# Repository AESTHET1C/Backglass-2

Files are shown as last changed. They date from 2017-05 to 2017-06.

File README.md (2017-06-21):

# Backglass 2 Pinball Controller Board

An Arduino Uno-compatible unified control board tailored to the Eli Whitney Museum 2017 summer pinball project.

The board contains the following hardware:

* Microchip ATmega8U2/16U2 (serial communication and code upload)
* Microchip ATmega328P (user code)
* Microchip ATmega48PB (audio/visual coprocessing)
* 4-character 7 segment display
* 2 analogue inputs (for reflectance sensors)
* 5 digital inputs (with integrated pull-ups)
* 3 current-limited LED outputs
* 1 PWM-controlled motor output
* 1 speaker output
* Micro USB interface
* 2.7 - 6.5 volt power input

All features of the board, with the exception of the motor, can be powered via USB.

-----

A user-oriented code library can be found here: <https://github.com/AESTHET1C/Backglass-2-Library/>

The coprocessor firmware can be found here: <https://github.com/AESTHET1C/Backglass-2-Firmware/>

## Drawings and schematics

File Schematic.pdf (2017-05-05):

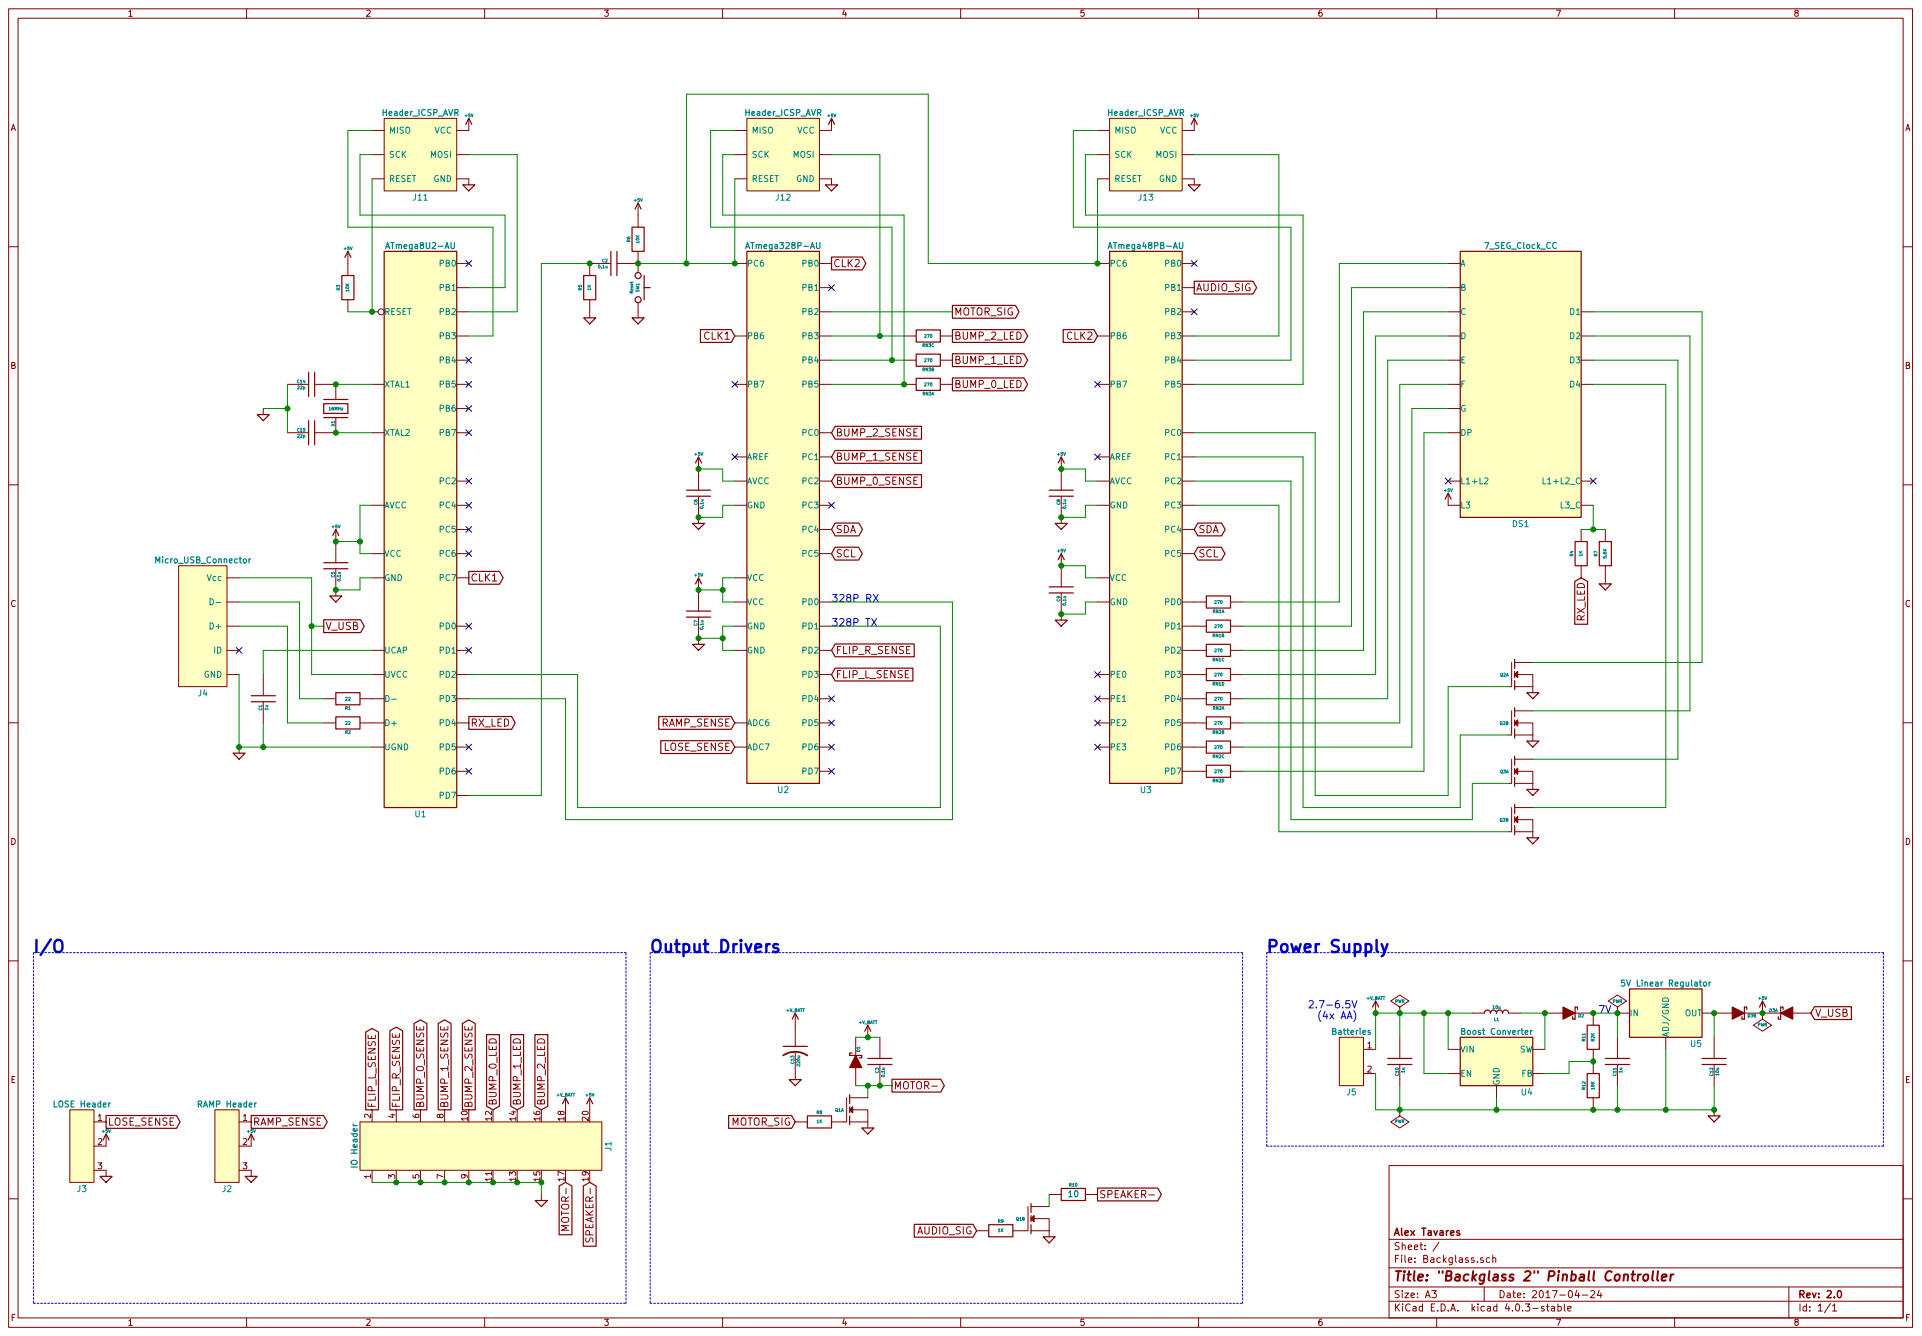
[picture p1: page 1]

9 1020 11 12 13 14 15 16 17 18 19 J1 IO Header FLIP_L_SENSE FLIP_R_SENSE BUMP_0_SENSE BUMP_1_SENSE BUMP_2_SENSE BUMP_0_LED BUMP_1_LED BUMP_2_LED SPEAKER- MOTOR-

File: Backglass.sch Sheet: / Alex Tavares

Id: 1/1 Title: "Backglass 2" Pinball Controller

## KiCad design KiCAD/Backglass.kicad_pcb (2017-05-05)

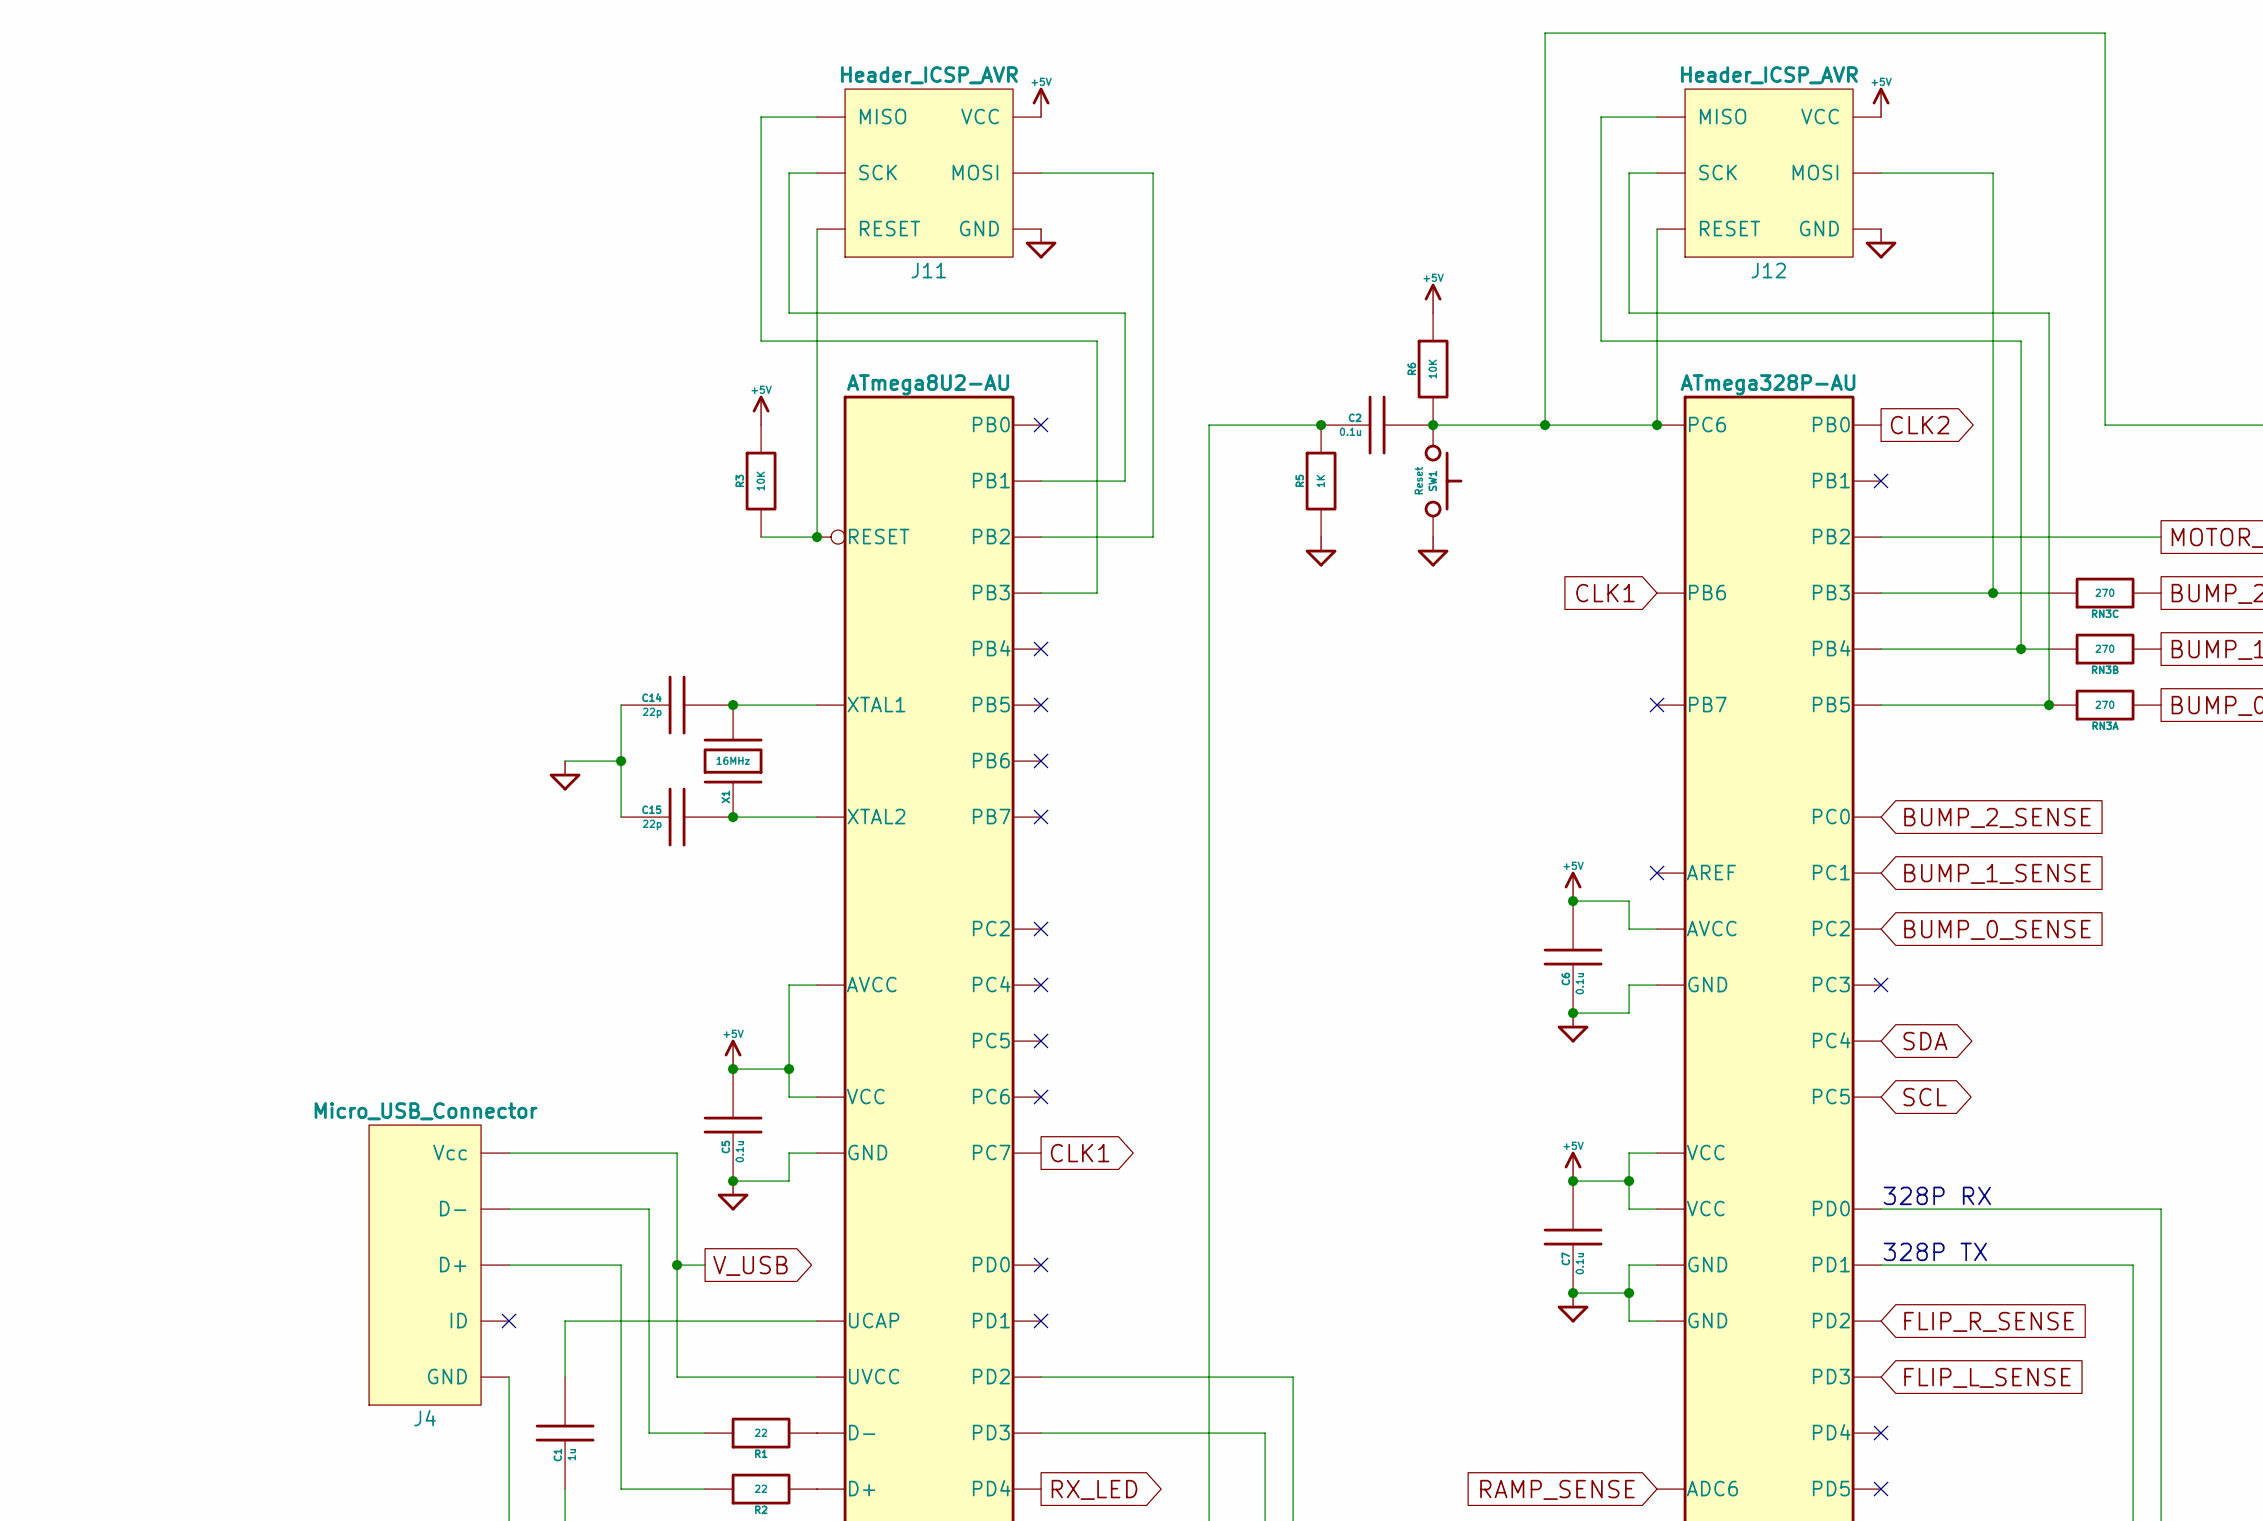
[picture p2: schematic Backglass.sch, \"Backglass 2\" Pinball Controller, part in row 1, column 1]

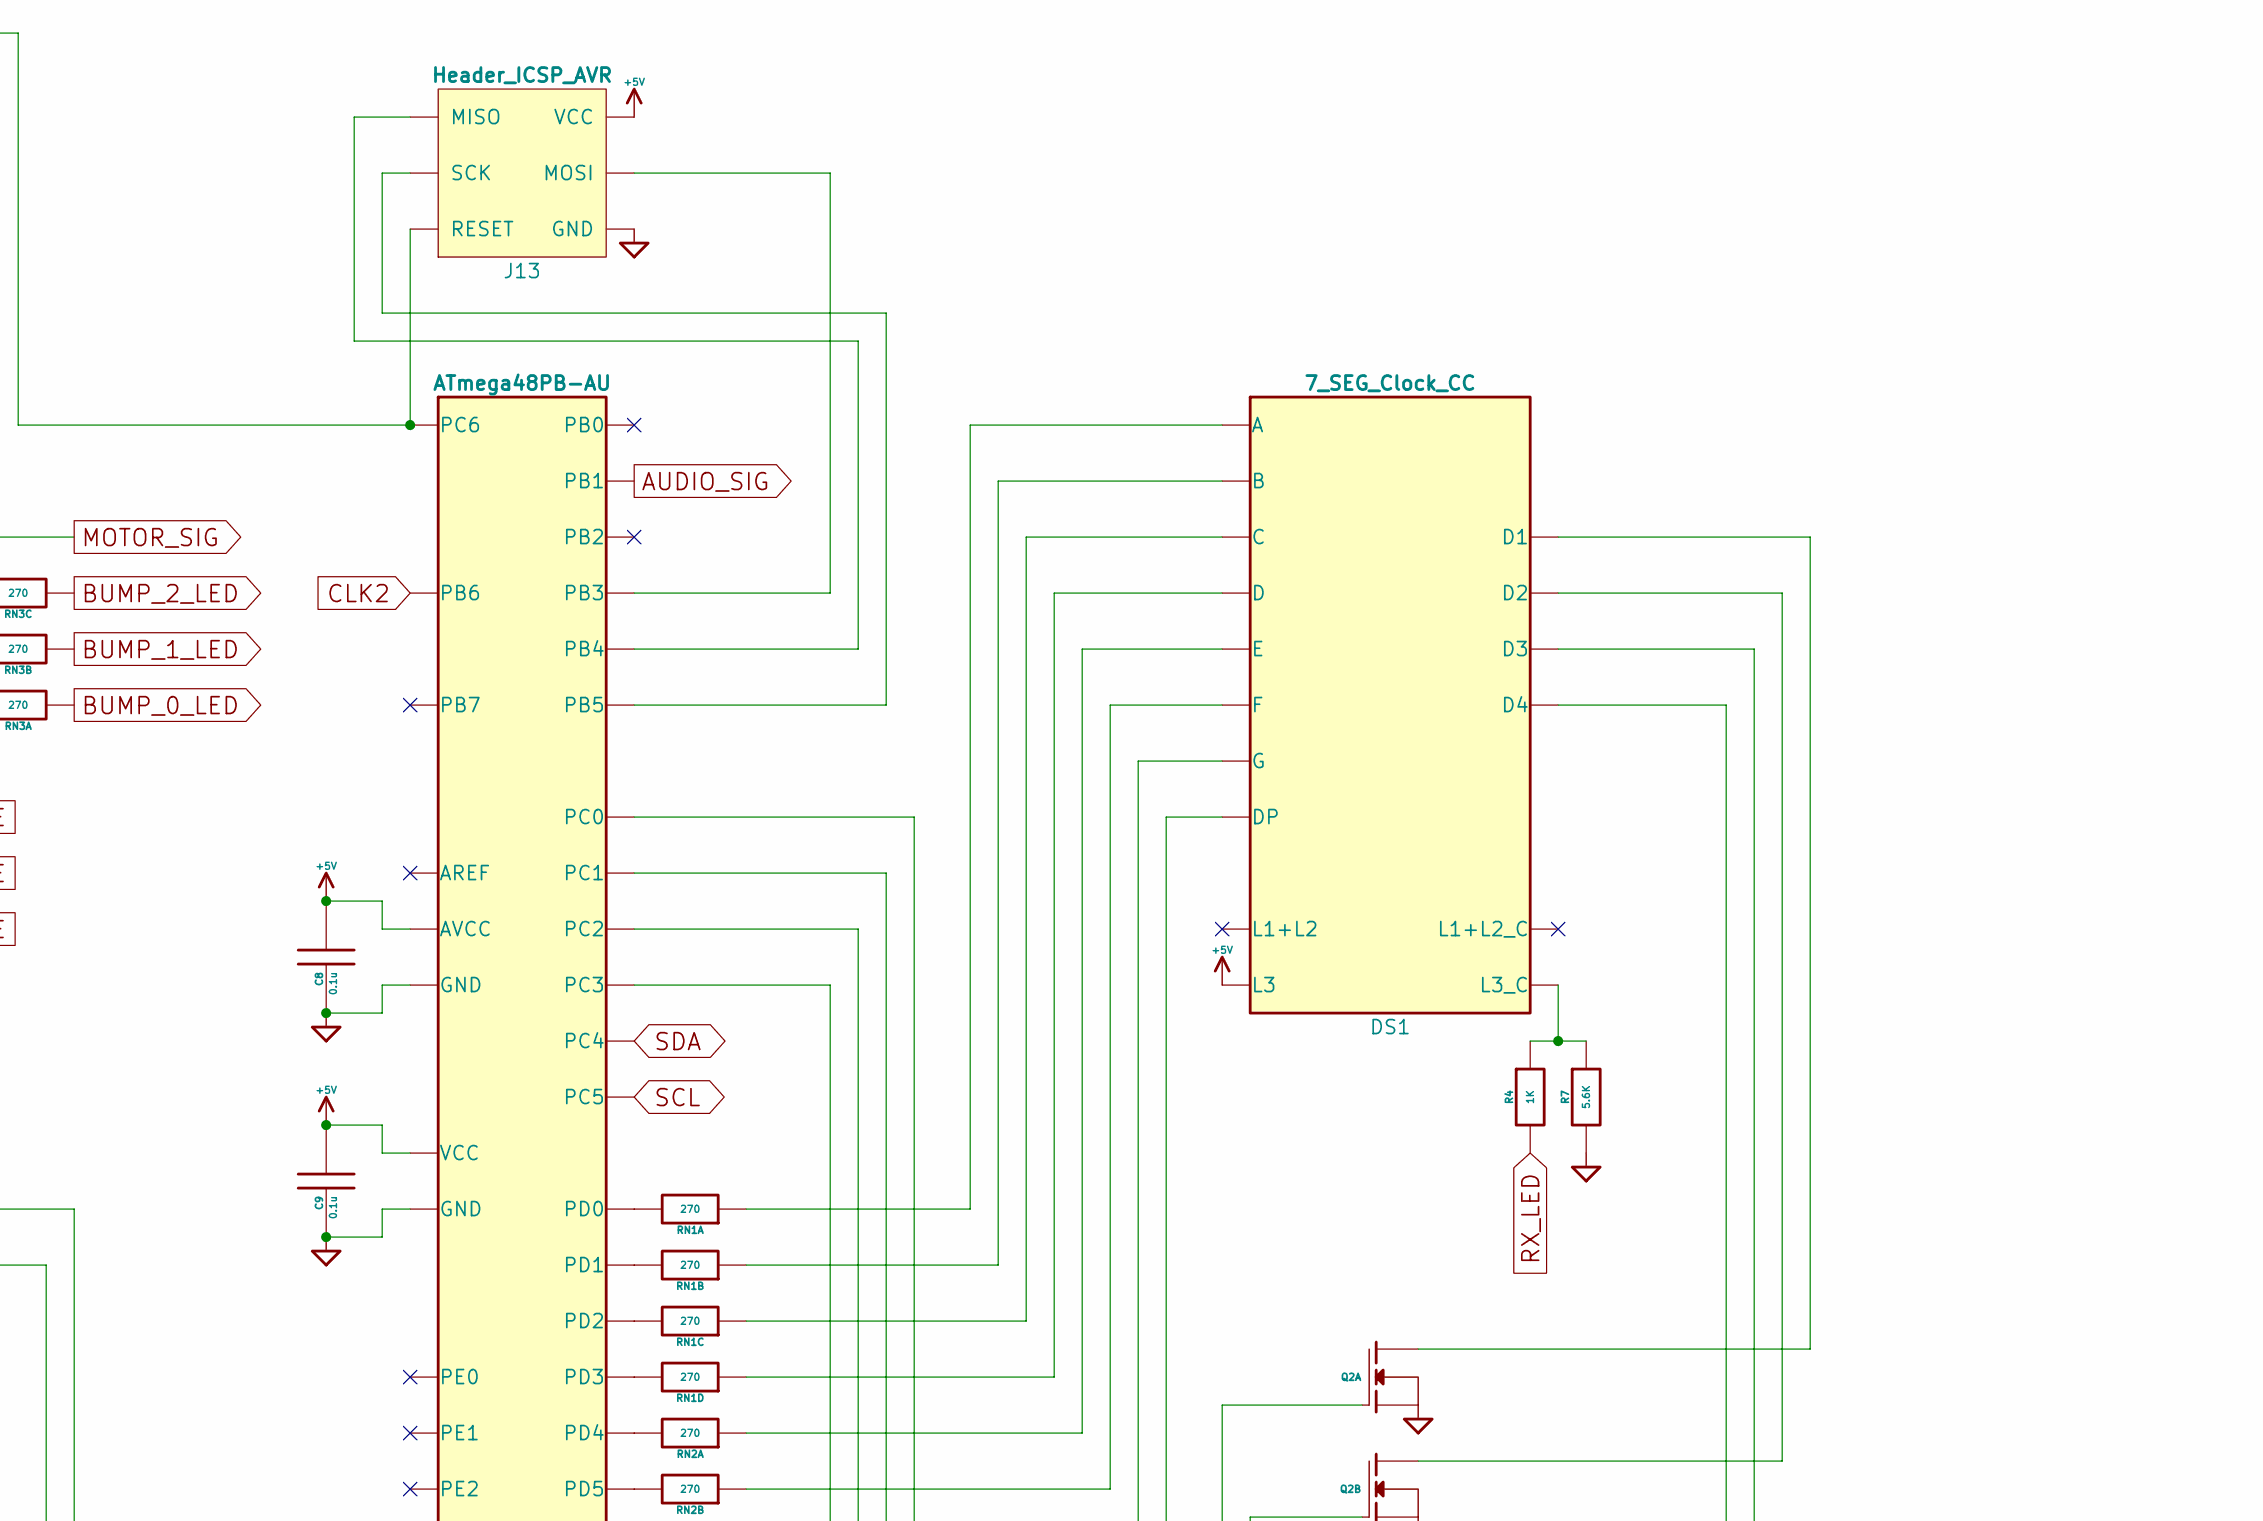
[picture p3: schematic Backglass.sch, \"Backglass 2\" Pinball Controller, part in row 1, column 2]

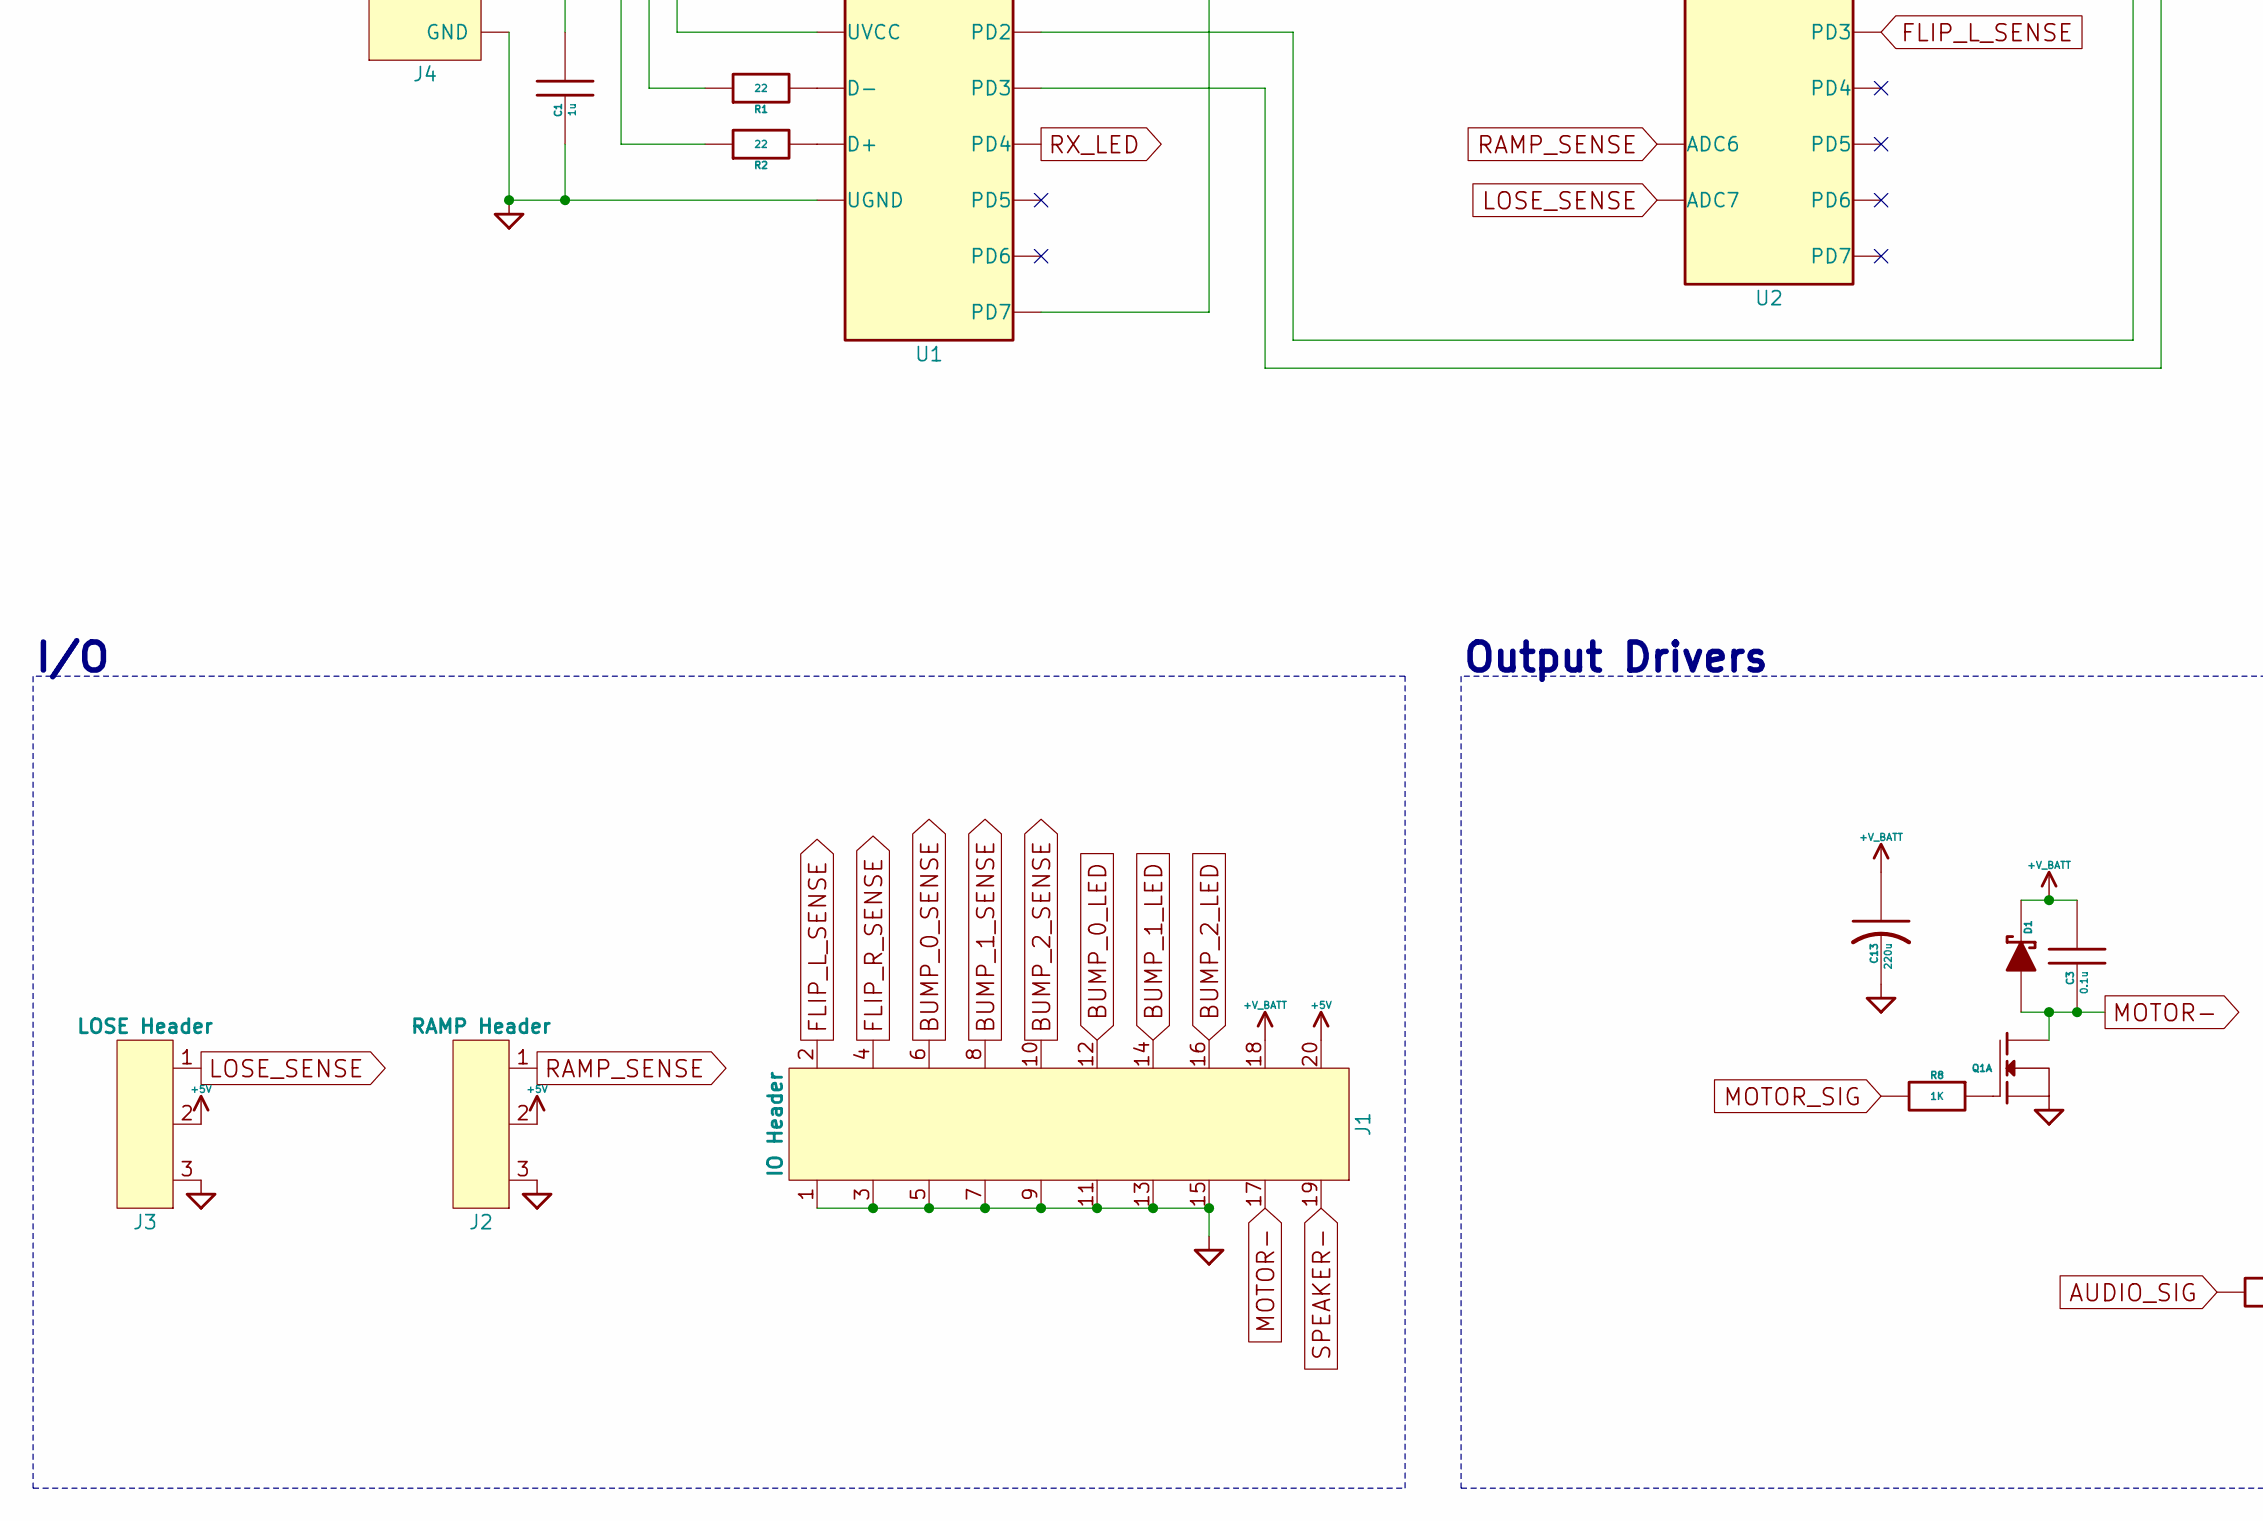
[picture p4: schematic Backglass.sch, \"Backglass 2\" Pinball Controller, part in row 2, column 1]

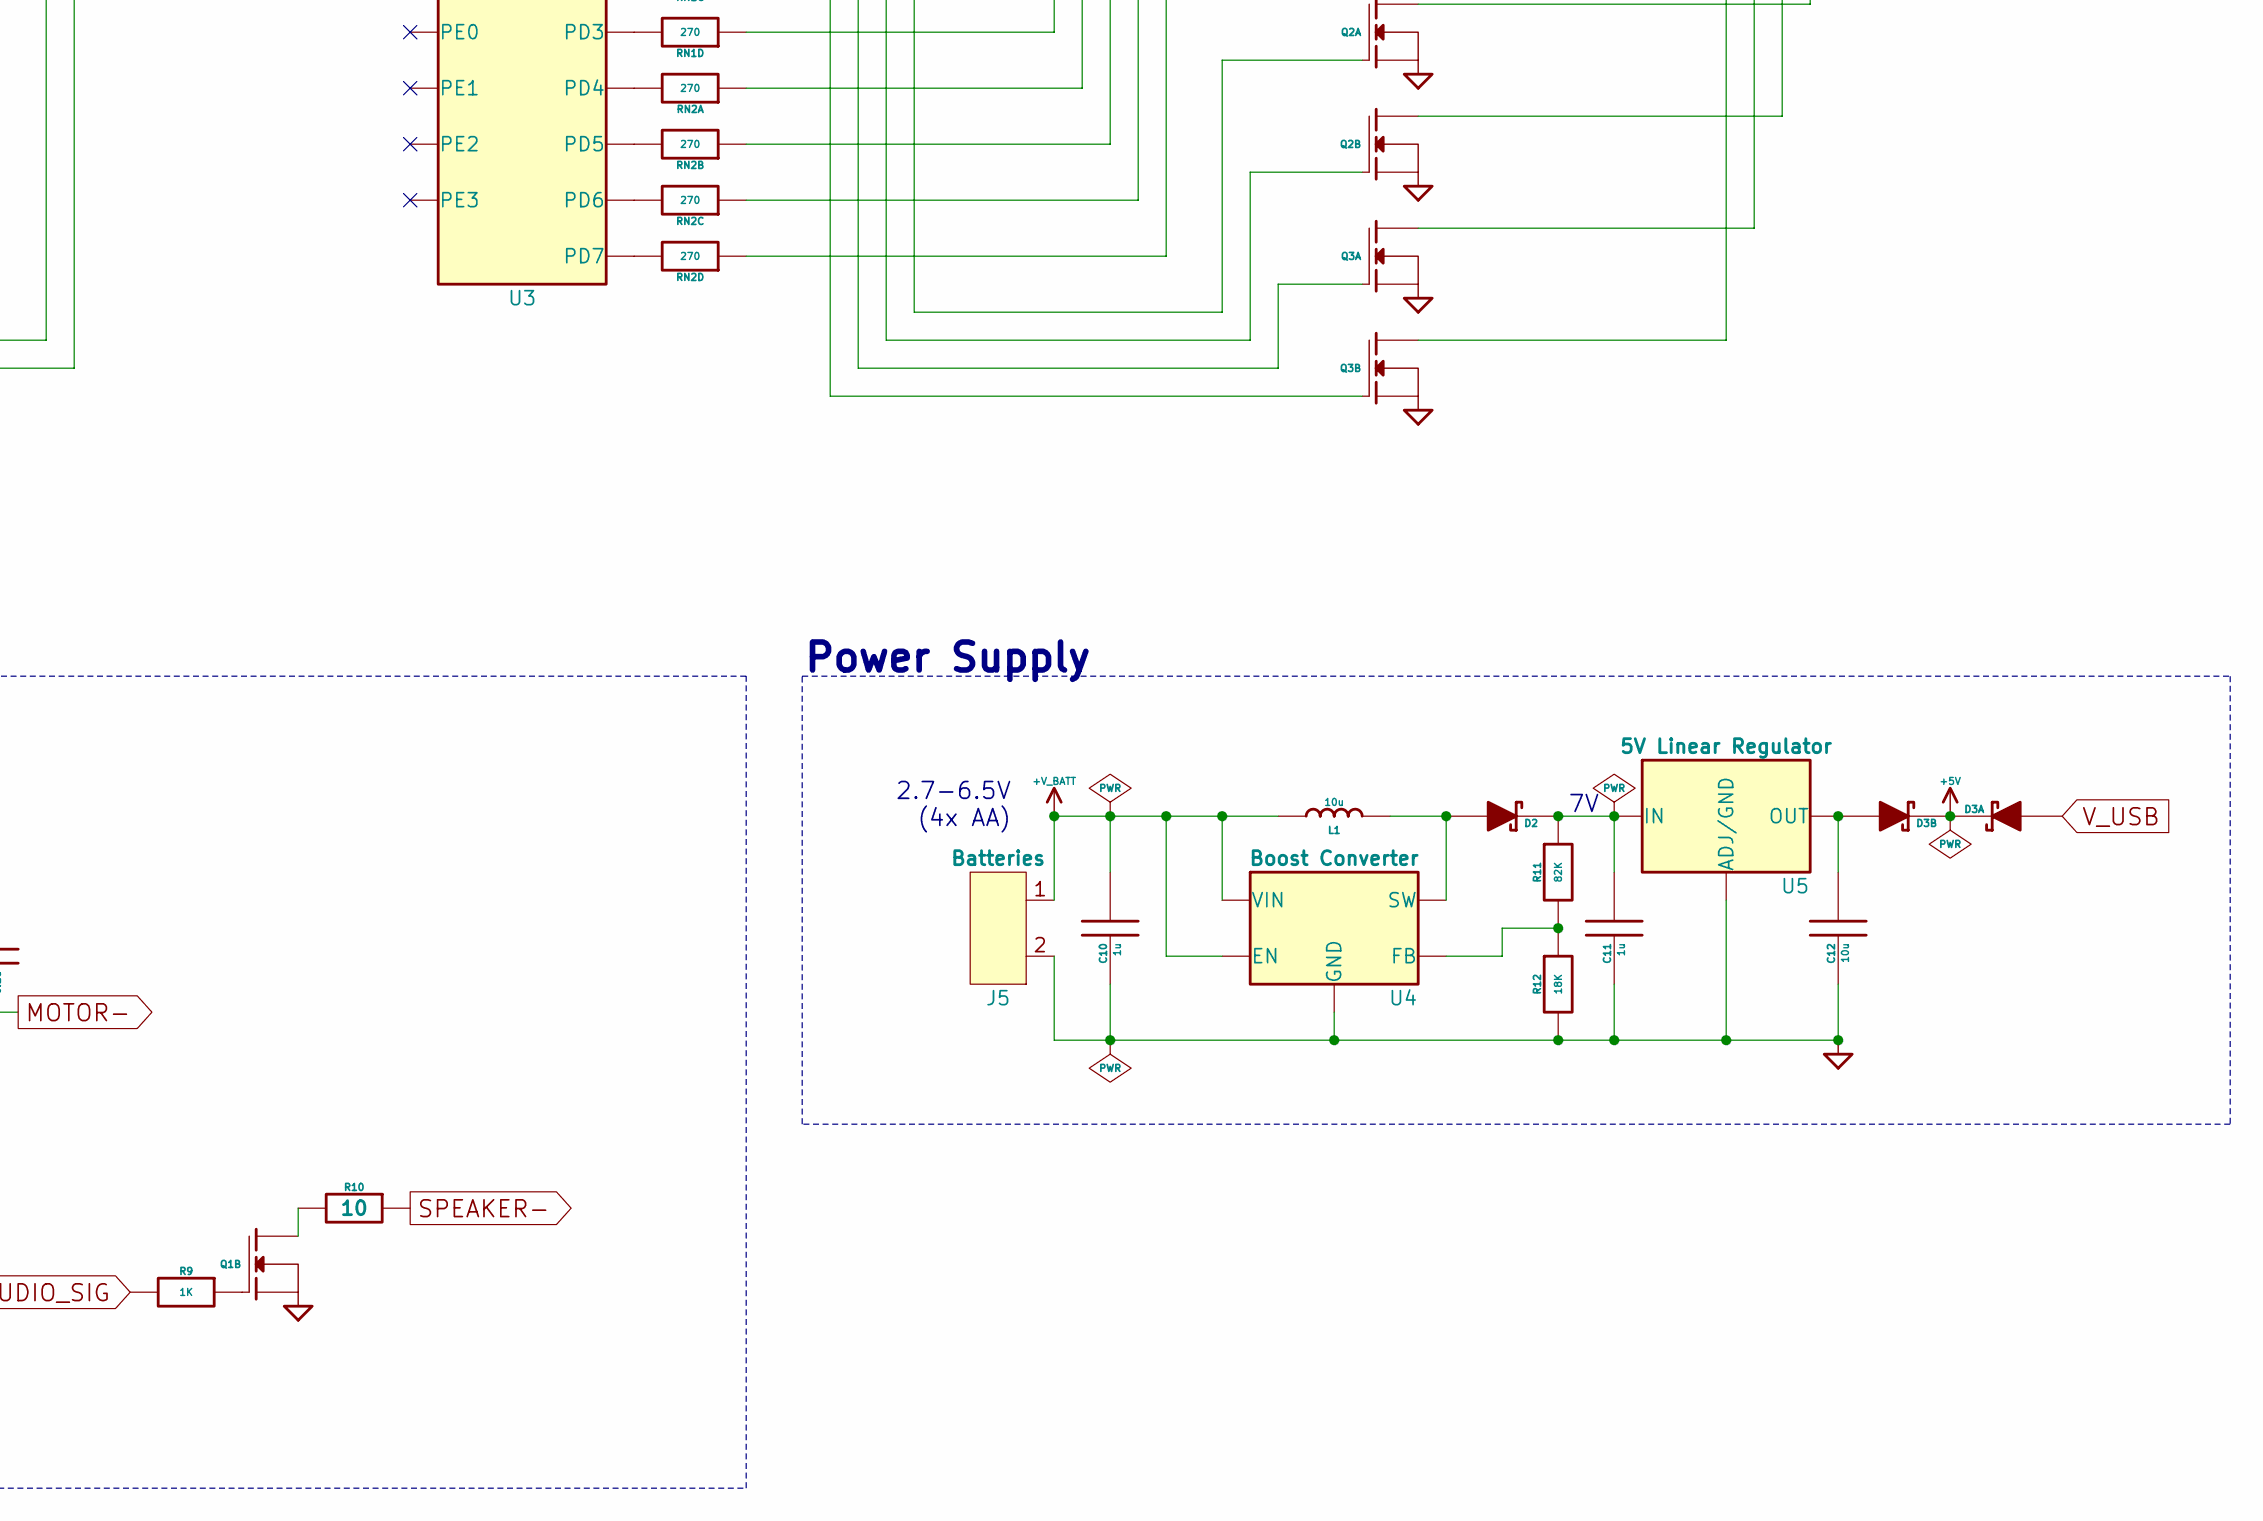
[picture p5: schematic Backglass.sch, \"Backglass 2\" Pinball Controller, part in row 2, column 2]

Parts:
C1, C10, C11: 1u; 1608
C2, C3, C5, C6, C7, C8, C9: 0.1u; 1608
C12: 10u; 2012
C13: 220u; C_6.3-2.5mm
C14, C15: 22p; 1608
D1, D2: D_Schottky; SOT-23-3_A-C
D3: D_Schottky_Dual_CC; SOT-23-3_AAC
DS1: 7_SEG_Clock_CC; TDCx10xxM
J1: IO Header; 10x2_0.1in
J2: RAMP Header; 3x1_0.1in
J3: LOSE Header; 3x1_0.1in
J4: Micro_USB_Connector; Molex_1051640001
J5: Batteries; 2x1_0.1in
J11, J12, J13: Header_ICSP_AVR; AVR_ICSP_0.05in
L1: 10u; 3225
Q1: MOSFET_N_E_Dual; SOT-23-6_G1-S2-G2-D2-S1-D1
Q2, Q3: MOSFET_N_E_Dual; TSSOP-6_S1-G1-D2-S2-G2-D1
R1, R2: 22; 1608
R3, R6: 10K; 1608
R4, R5, R8, R9: 1K; 1608
R7: 5.6K; 1608
R10: 10; 3225
R11: 82K; 1608
R12: 18K; 1608
RN1, RN2, RN3: 270; Array_4x1608_Convex_NP
SW1: Reset; Tact_Switch_6mm
U1: ATmega8U2-AU; TQFP-32
U2: ATmega328P-AU; TQFP-32
U3: ATmega48PB-AU; TQFP-32
U4: Boost Converter; SOT-23-5
U5: 5V Linear Regulator; SOT-223-4
X1: 16MHz; 3.2x2.5_SMD_CRYSTAL

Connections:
+5V: C5.2, C6.2, C7.2, C8.2, C9.2, D3.C, DS1.9 (L3), J1.20, J2.2, J3.2, J11.2 (VCC), J12.2 (VCC), J13.2 (VCC), R3.1, R6.1, U1.4 (VCC), U1.32 (AVCC), U2.4 (VCC), U2.6 (VCC), U2.18 (AVCC), U3.4 (VCC), U3.18 (AVCC)
+V_BATT: C3.2, C10.2, C13.1, D1.C, J1.18, J5.1, L1.1, U4.4 (EN), U4.5 (VIN)
AUDIO_SIG: R9.2, U3.13 (PB1)
BUMP_0_LED: J1.12, RN3.8
BUMP_0_SENSE: J1.6, U2.25 (PC2)
BUMP_1_LED: J1.14, RN3.7
BUMP_1_SENSE: J1.8, U2.24 (PC1)
BUMP_2_LED: J1.16, RN3.6
BUMP_2_SENSE: J1.10, U2.23 (PC0)
CLK1: U1.22 (PC7), U2.7 (PB6)
CLK2: U2.12 (PB0), U3.7 (PB6)
FLIP_L_SENSE: J1.2, U2.1 (PD3)
FLIP_R_SENSE: J1.4, U2.32 (PD2)
GND: C1.1, C5.1, C6.1, C7.1, C8.1, C9.1, C10.1, C11.1, C12.1, C13.2, C14.1, C15.1, J1.1, J1.3, J1.5, J1.7, J1.9, J1.11, J1.13, J1.15, J2.3, J3.3, J4.5 (GND), J5.2, J11.6 (GND), J12.6 (GND), J13.6 (GND), Q1.S1, Q1.S2, Q2.S1, Q2.S2, Q3.S1, Q3.S2, R5.2, R7.2, R12.2, SW1.2 (NO), U1.3 (GND), U1.28 (UGND), U2.3 (GND), U2.5 (GND), U2.21 (GND), U3.5 (GND), U3.21 (GND), U4.2 (GND), U5.1 (ADJ/GND)
LOSE_SENSE: J3.1, U2.22 (ADC7)
MOTOR-: C3.1, D1.A, J1.17, Q1.D1
MOTOR_SIG: R8.2, U2.14 (PB2)
unnamed: C1.2, U1.27 (UCAP)
unnamed: C2.1, R5.1, U1.13 (PD7)
unnamed: C2.2, J12.5 (RESET), J13.5 (RESET), R6.2, SW1.1 (C), U2.29 (PC6), U3.29 (PC6)
unnamed: C11.2, D2.C, R11.1, U5.3 (IN)
unnamed: C12.2, D3.A2, U5.2 (OUT), U5.4
unnamed: C14.2, U1.1 (XTAL1), X1.2
unnamed: C15.2, U1.2 (XTAL2), X1.1
unnamed: D2.A, L1.2, U4.1 (SW)
unnamed: DS1.1 (D1), Q2.D1
unnamed: DS1.2 (D2), Q2.D2
unnamed: DS1.3 (D), RN1.4
unnamed: DS1.5 (E), RN2.1
unnamed: DS1.6 (D3), Q3.D1
unnamed: DS1.7 (DP), RN2.4
unnamed: DS1.8 (D4), Q3.D2
unnamed: DS1.10 (L3_C), R4.1, R7.1
unnamed: DS1.11 (F), RN2.2
unnamed: DS1.13 (C), RN1.3
unnamed: DS1.14 (A), RN1.1
unnamed: DS1.15 (G), RN2.3
unnamed: DS1.16 (B), RN1.2
unnamed: J4.2 (D-), R1.1
unnamed: J4.3 (D+), R2.1
unnamed: J11.1 (MISO), U1.17 (PB3)
unnamed: J11.3 (SCK), U1.15 (PB1)
unnamed: J11.4 (MOSI), U1.16 (PB2)
unnamed: J11.5 (RESET), R3.2, U1.24 (RESET)
unnamed: J12.1 (MISO), RN3.2, U2.16 (PB4)
unnamed: J12.3 (SCK), RN3.1, U2.17 (PB5)
unnamed: J12.4 (MOSI), RN3.3, U2.15 (PB3)
unnamed: J13.1 (MISO), U3.16 (PB4)
unnamed: J13.3 (SCK), U3.17 (PB5)
unnamed: J13.4 (MOSI), U3.15 (PB3)
unnamed: Q1.D2, R10.2
unnamed: Q1.G1, R8.1
unnamed: Q1.G2, R9.1
unnamed: Q2.G1, U3.23 (PC0)
unnamed: Q2.G2, U3.24 (PC1)
unnamed: Q3.G1, U3.25 (PC2)
unnamed: Q3.G2, U3.26 (PC3)
unnamed: R1.2, U1.30 (D-)
unnamed: R2.2, U1.29 (D+)
unnamed: R11.2, R12.1, U4.3 (FB)
unnamed: RN1.5, U3.1 (PD3)
unnamed: RN1.6, U3.32 (PD2)
unnamed: RN1.7, U3.31 (PD1)
unnamed: RN1.8, U3.30 (PD0)
unnamed: RN2.5, U3.11 (PD7)
unnamed: RN2.6, U3.10 (PD6)
unnamed: RN2.7, U3.9 (PD5)
unnamed: RN2.8, U3.2 (PD4)
unnamed: U1.8 (PD2), U2.31 (PD1)
unnamed: U1.9 (PD3), U2.30 (PD0)
RAMP_SENSE: J2.1, U2.19 (ADC6)
RX_LED: R4.2, U1.10 (PD4)
SCL: U2.28 (PC5), U3.28 (PC5)
SDA: U2.27 (PC4), U3.27 (PC4)
SPEAKER-: J1.19, R10.1
V_USB: D3.A1, J4.1 (Vcc), U1.31 (UVCC)

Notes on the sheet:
328P RX
328P TX
2.7-6.5V (4x AA)
Power Supply
I/O
Output Drivers

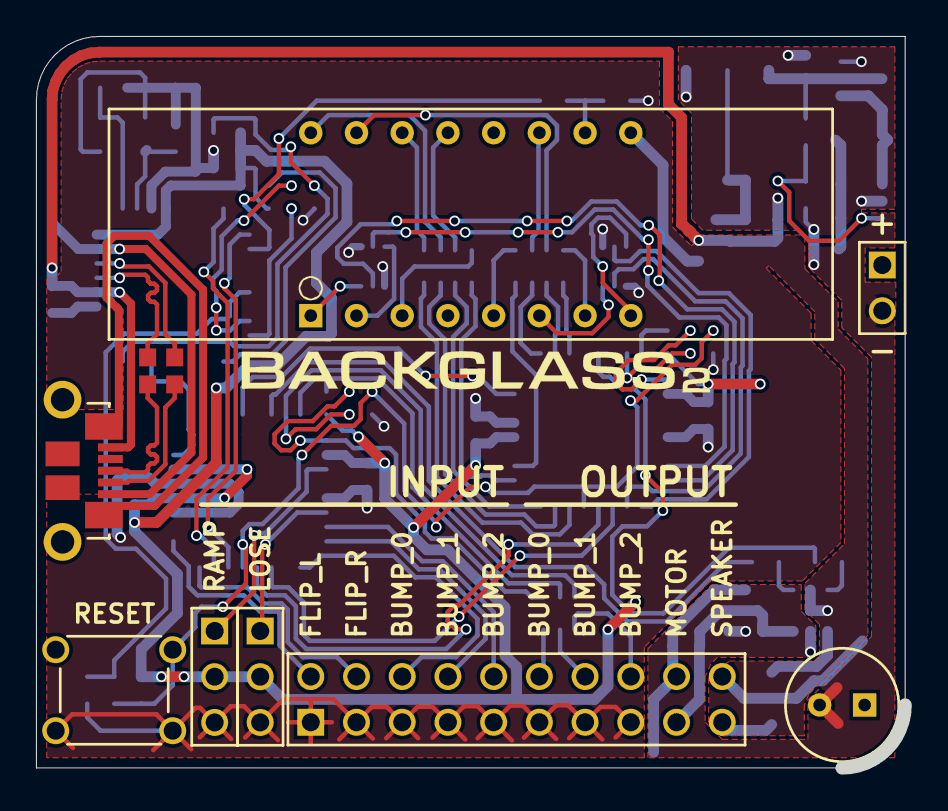
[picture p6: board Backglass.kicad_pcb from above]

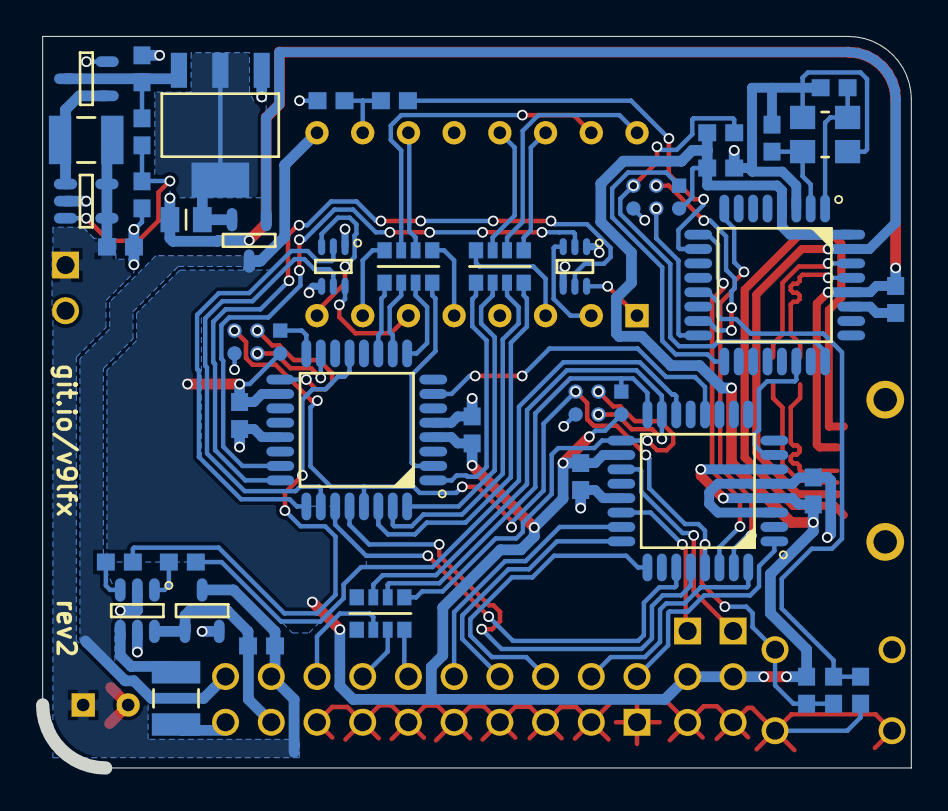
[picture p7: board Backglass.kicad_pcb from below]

Board: 2 copper layers, 48.3 x 40.6 mm, 52 parts (42 on the bottom side), 76 nets.

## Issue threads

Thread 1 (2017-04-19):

Missing mounting method

AESTHET1C, 2017-04-19:
Unlike the original Backglass board, there is no efficient way of mounting the board to the pinball machine.

AESTHET1C, 2017-05-05:
Mounting is to be handled either by hot glue or 3d-printed clips. I didn't feel like moving things around to fit mounting holes for the second revision, and I'm certainly not spinning a third revision just for that.

Closed 2017-05-05.

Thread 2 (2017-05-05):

Speaker driver causes reset on transition

AESTHET1C, 2017-05-05:
You did a bad job designing the half bridge and you should feel bad. Shoot-through is the first thing you should have considered when opting for bi-directional drive.

AESTHET1C, 2017-05-05:
The half bridge speaker drive has been removed and replaced with a boring single-transistor alternative for revision 2.0.

Closed 2017-05-05.

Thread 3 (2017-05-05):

Speaker output has DC offset

AESTHET1C, 2017-05-05:
Uni-directional drive and lack of AC coupling means speaker will always be driven positively. This may lead to long-term speaker damage.

Closed 2017-05-05.

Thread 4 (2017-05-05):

I2C lines lack pullups

AESTHET1C, 2017-05-05:

AESTHET1C, 2017-05-05:
I forgot to add pullups to the first revision of the board, and didn't feel like moving things around for the second revision.

Using the weak internal pullups of the ATmega48PB is sufficient in this case.

Closed 2017-05-05.

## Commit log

2017-04-19 Initial upload
    Added basic KiCAD files, gerbers, schematic PDF, and vague readme
    describing the board.
    [Backglass-B.Cu.gbl, Backglass-B.Mask.gbs, Backglass-B.SilkS.gbo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]
2017-05-05 Fixed audio output, reduced power consumption
    Removed half-bridge and associated components, modified resistor values
    to drive LEDs dimmer (and now within power specs for the 48PB).
    [Backglass-B.Cu.gbl, Backglass-B.Mask.gbs, Backglass-B.SilkS.gbo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]
